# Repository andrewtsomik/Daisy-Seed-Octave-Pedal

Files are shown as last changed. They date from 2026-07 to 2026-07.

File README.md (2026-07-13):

# Daisy Seed Octave Pedal

Using a Daisy Seed microcontroller, simulate an octave effects pedal for electric bass!
## Features

- **Sub octave** (-12 semitones) and **upper octave** (+12 semitones), each with its own level control
- **Envelope-gated** octave voices with hysteresis, so quiet passages and note decay don't produce gate chatter/zipper noise
- **Latching footswitch** one tap turns the effect on, another tap bypasses it
- Onboard LED tracks your playing envelope in real time
- True bypass fallback: bypassed signal is the untouched dry input
## Hardware
 
| Component | Daisy Seed Pin | Purpose |
|---|:---:|---|
| Pot 1 | A0 | Dry level |
| Pot 2 | A1 | Sub-octave level |
| Pot 3 | A2 | Upper-octave level |
| Footswitch | D18 | Effect on/off (momentary, wired to pull-up, active low) |
| LED | D19 | Envelope indicator |
| Input Jack | A16 | Bass Input |
| Output Jack | A18 | Amp Output |
| DC Jack | A39 | Power Source |

## Schematic



## PCB Layout



## Fabricated and Assembled Design

### Front


### Back


### Assembled


## Demo (Don't hate I suck lol)

### Toggled On

https://github.com/user-attachments/assets/edada847-4ac4-451e-820c-bb3a319f9780

### Toggled Off

https://github.com/user-attachments/assets/274790b7-3237-4e18-9de3-0ea1d50deda9

## Flashing Instructions
Pre-Step 1
Run the commands below if you have not already cloned the libraries needed
```bash
git clone --recursive https://github.com/electro-smith/libDaisy.git
git clone --recursive https://github.com/electro-smith/DaisySP.git
```

1. Hold down the BOOT button your Daisy Seed
2. Press and release the RESET button
3. Release the BOOT button
4. Run the following command (Getting Error 74 is normal and a sign everything is working)

```bash
make clean && make && make program-dfu
```

5. Press and release the RESET button again

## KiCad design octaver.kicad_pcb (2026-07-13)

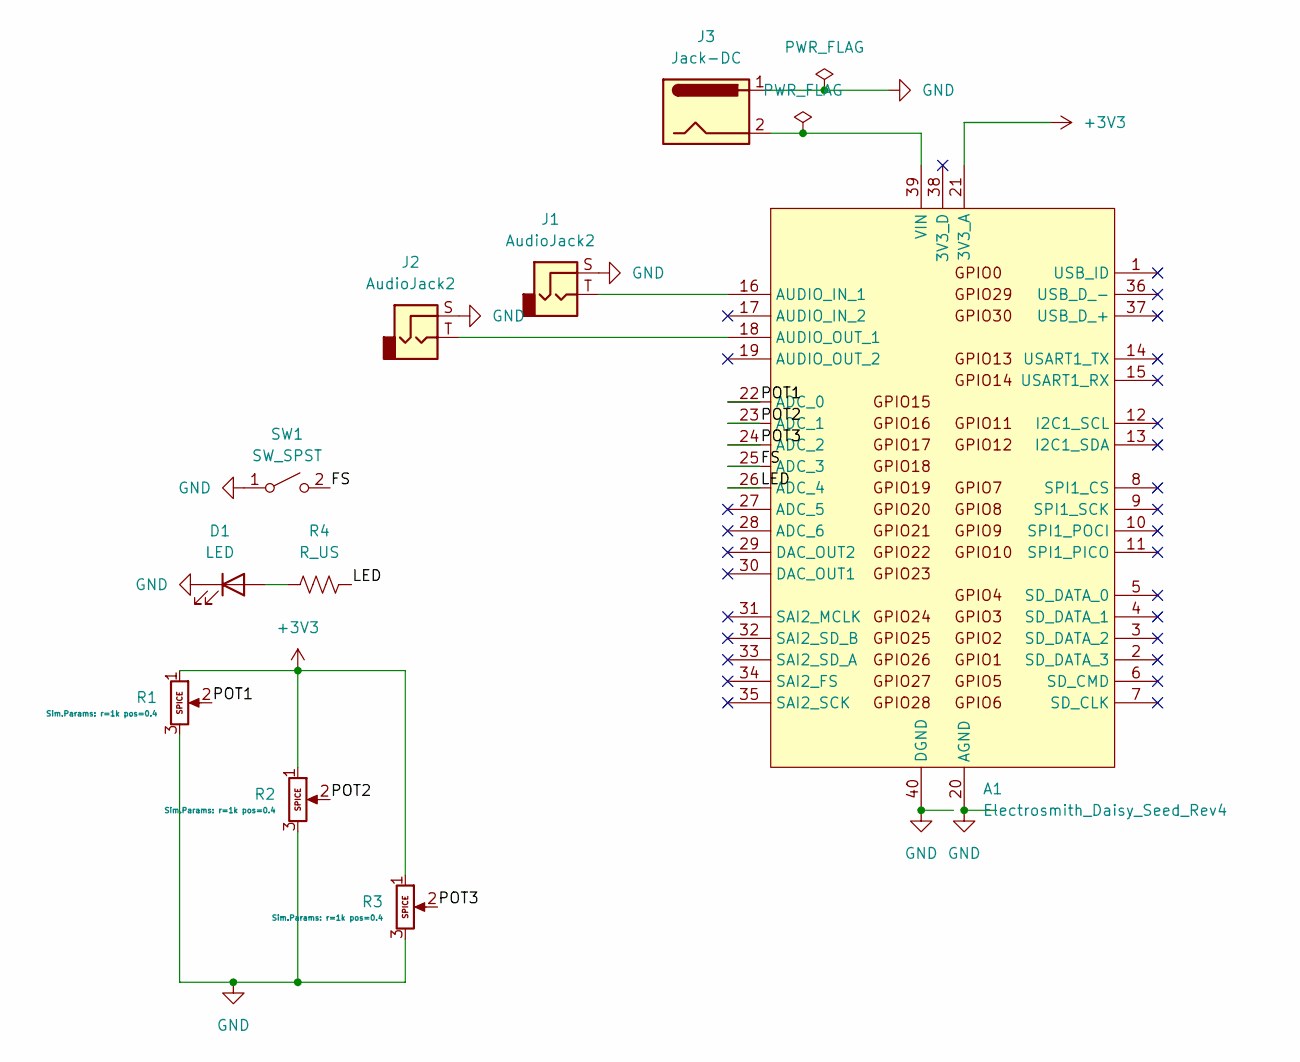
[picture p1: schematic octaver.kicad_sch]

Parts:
A1: Electrosmith_Daisy_Seed_Rev4; Electrosmith_Daisy_Seed
D1: LED; LED_D5.0mm
J1, J2: AudioJack2; SolderWire-0.5sqmm_1x02_P4.6mm_D0.9mm_OD2.1mm
J3: Jack-DC; SolderWire-0.5sqmm_1x02_P4.6mm_D0.9mm_OD2.1mm
R1, R2, R3: Potentiometer; Potentiometer_Alps_RK163_Single_Horizontal
R4: R_US; R_Axial_DIN0207_L6.3mm_D2.5mm_P7.62mm_Horizontal
SW1: SW_SPST; SolderWire-0.5sqmm_1x02_P4.6mm_D0.9mm_OD2.1mm

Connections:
+3V3: A1.21 (3V3_A), R1.1, R2.1, R3.1
/FS: A1.25 (ADC_3), SW1.2 (B)
/LED: A1.26 (ADC_4), R4.1
/POT1: A1.22 (ADC_0), R1.2
/POT2: A1.23 (ADC_1), R2.2
/POT3: A1.24 (ADC_2), R3.2
GND: A1.20 (AGND), A1.40 (DGND), D1.1 (K), J1.S, J2.S, J3.1, R1.3, R2.3, R3.3, SW1.1 (A)
unnamed: A1.16 (AUDIO_IN_1), J1.T
unnamed: A1.18 (AUDIO_OUT_1), J2.T
unnamed: A1.39 (VIN), J3.2
unnamed: D1.2 (A), R4.2

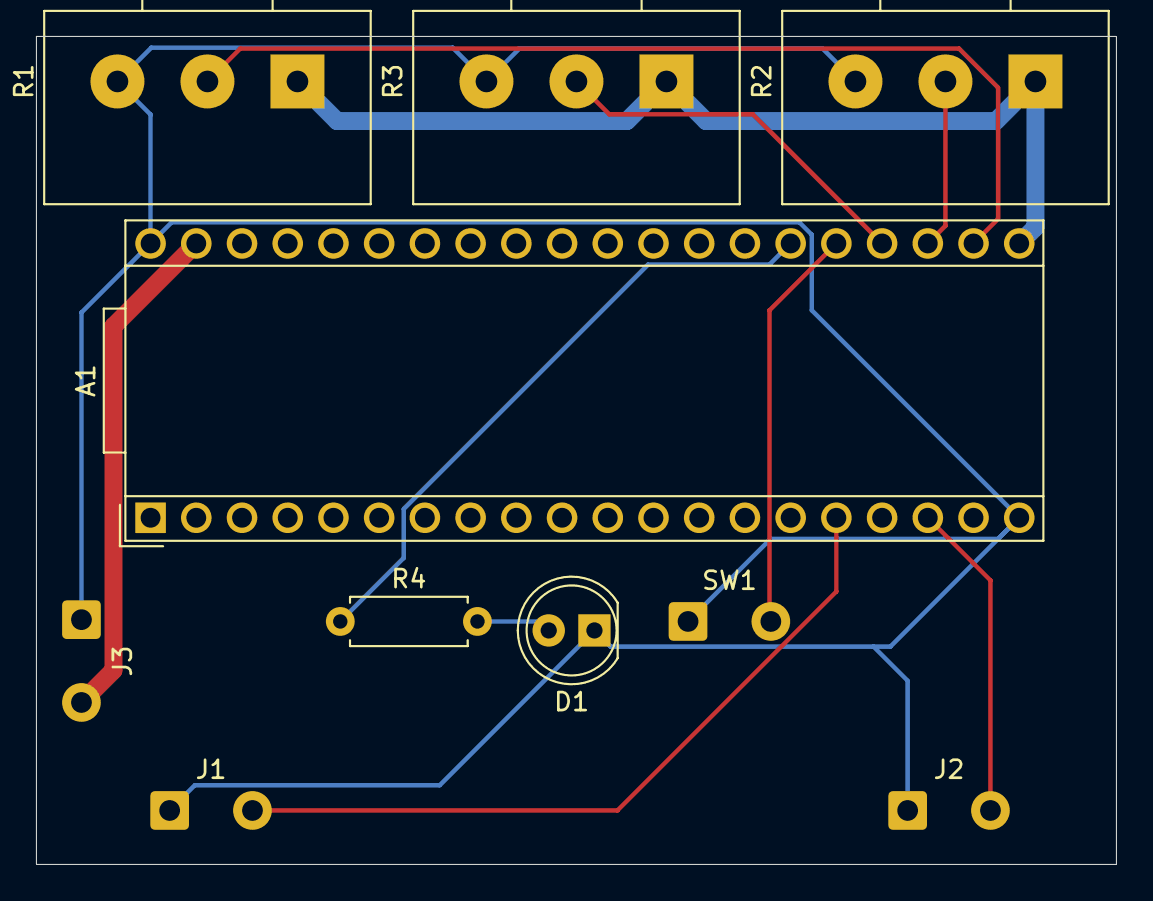
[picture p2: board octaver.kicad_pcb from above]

Board: 2 copper layers, 60.0 x 46.0 mm, 10 parts (0 on the bottom side), 11 nets.

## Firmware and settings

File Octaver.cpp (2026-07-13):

#include "daisy_seed.h"
#include "daisysp.h"
 
using namespace daisy;
using namespace daisy::seed;
using namespace daisysp;
 
#define POT1 A0
#define POT2 A1
#define POT3 A2
#define LED1  D19
#define FS_SWITCH  D18
 
enum AdcChannel
{
	PotOne,
	PotTwo,
	PotThree,
	NUM_ADC_CHANNELS
};
 
DaisySeed hw;
 
PitchShifter sub_shift;
PitchShifter upper_shift;
OnePole env_lpf;
Led led_gate;
Switch footswitch;
 
static constexpr float ENV_THRESHOLD_OPEN  = 0.01f;
static constexpr float ENV_THRESHOLD_CLOSE = 0.006f;
static constexpr float GATE_SMOOTH_COEFF   = 0.01f;
static constexpr float SMOOTH              = 0.002f;
 
float dry_smooth   = 0.7f;
float sub_smooth   = 0.8f;
float upper_smooth = 0.0f;
 
static bool  gate_state  = false;
static float gate_smooth = 0.0f;
 
static bool effect_on         = false;
static bool footswitch_last   = false;
 
void AudioCallback(AudioHandle::InputBuffer in, AudioHandle::OutputBuffer out, size_t size)
{
	bool footswitch_pressed = footswitch.Pressed();
	if(footswitch_pressed && !footswitch_last)
	{
		effect_on = !effect_on;
	}
	footswitch_last = footswitch_pressed;
 
	float pot_dry   = hw.adc.GetFloat(0);
	float pot_sub   = hw.adc.GetFloat(1);
	float pot_upper = hw.adc.GetFloat(2);
 
	dry_smooth   += SMOOTH * (pot_dry - dry_smooth);
	sub_smooth   += SMOOTH * (pot_sub - sub_smooth);
	upper_smooth += SMOOTH * (pot_upper - upper_smooth);
 
	for(size_t i = 0; i < size; i++)
	{
		float input = in[0][i];
 
		float rectified = fabsf(input);
		float envelope   = env_lpf.Process(rectified);
 
		if(!gate_state && envelope > ENV_THRESHOLD_OPEN)
		{
			gate_state = true;
		}
		else if(gate_state && envelope < ENV_THRESHOLD_CLOSE)
		{
			gate_state = false;
		}
 
		float gate_target = gate_state ? 1.0f : 0.0f;
		gate_smooth += GATE_SMOOTH_COEFF * (gate_target - gate_smooth);
 
		led_gate.Set(fclamp(envelope * 8.0f, 0.0f, 1.0f));
 
		float sub_out   = sub_shift.Process(input) * gate_smooth;
		float upper_out = upper_shift.Process(input) * gate_smooth;
 
		float mixed;
		if(effect_on)
		{
			mixed = input * dry_smooth + sub_out * sub_smooth + upper_out * upper_smooth;
			mixed = mixed / (1.0f + fabsf(mixed));
		}
		else
		{
			mixed = input;
		}
 
		out[0][i] = mixed;
		out[1][i] = mixed;
	}
}
 
int main(void)
{
	hw.Init();
	hw.SetAudioBlockSize(4);
	hw.SetAudioSampleRate(SaiHandle::Config::SampleRate::SAI_48KHZ);
 
	float sample_rate = hw.AudioSampleRate();
 
	AdcChannelConfig adc_cfg[NUM_ADC_CHANNELS];
	adc_cfg[PotOne].InitSingle(POT1);
	adc_cfg[PotTwo].InitSingle(POT2);
	adc_cfg[PotThree].InitSingle(POT3);
	hw.adc.Init(adc_cfg, NUM_ADC_CHANNELS);
	hw.adc.Start();
 
	sub_shift.Init(sample_rate);
	sub_shift.SetTransposition(-12.0f);
	sub_shift.SetFun(0.0f);
 
	upper_shift.Init(sample_rate);
	upper_shift.SetTransposition(12.0f);
	upper_shift.SetFun(0.0f);
 
	env_lpf.Init();
	env_lpf.SetFrequency(20.0f / sample_rate);
 
	led_gate.Init(LED1, false);
 
	footswitch.Init(FS_SWITCH, 1000.0f, Switch::TYPE_MOMENTARY, Switch::POLARITY_INVERTED, Switch::PULL_UP);
 
	hw.StartAudio(AudioCallback);
 
	while(1)
	{
		footswitch.Debounce();
		led_gate.Update();
		System::Delay(1);
	}
}
